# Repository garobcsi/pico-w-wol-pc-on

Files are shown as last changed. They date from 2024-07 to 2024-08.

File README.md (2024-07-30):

# Turn on your pc useing a raspberry pico-w

## Main goal of the project

Some motherboards dosent support wol or just dosent always work,
but useing a pico as the wol reciver (the pico connects to wifi) you could turn on your pc from anywhere in the world if you use port forwarding on your router.

## Thecnical side

### main.c

In `#define` setup your `SSID` `PASSWORD` and your `GPIO_PIN` number has to be configured and then build the firmweare.

#### Building the firmweare

```
cd code
cmake .
make
```

### The pico and motherboard

When the pico recives a magic packet it send a signal to the optocoupler (the pico cannot be on the same ground as your pc) and briges the power button and turns on the pc. But thers a pass truh port that you plug in your existing pc's power button so the pc's power button dosent lose it's function. And the pc can be turn on by existing button and by the pcio.

`Wol in`: pico gpio input
`BT in`: pc case power button
`FP out`: front panel out

## Motherboard pics

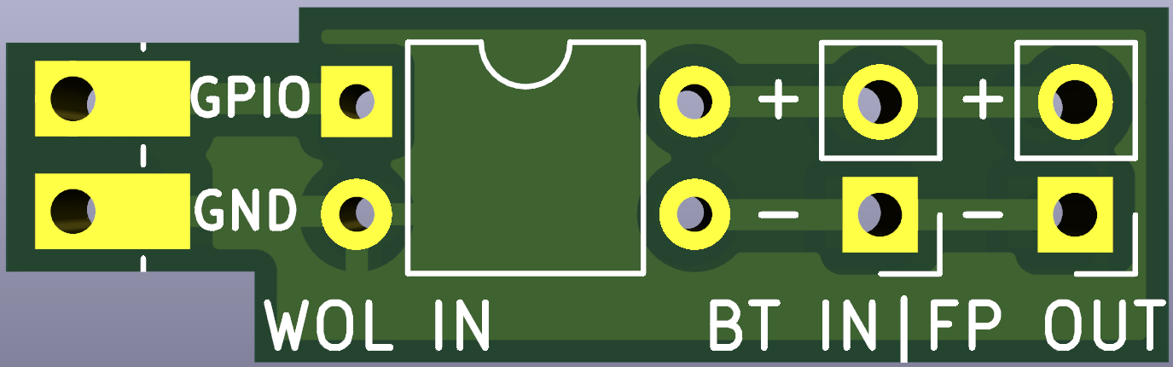
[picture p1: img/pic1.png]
mobo

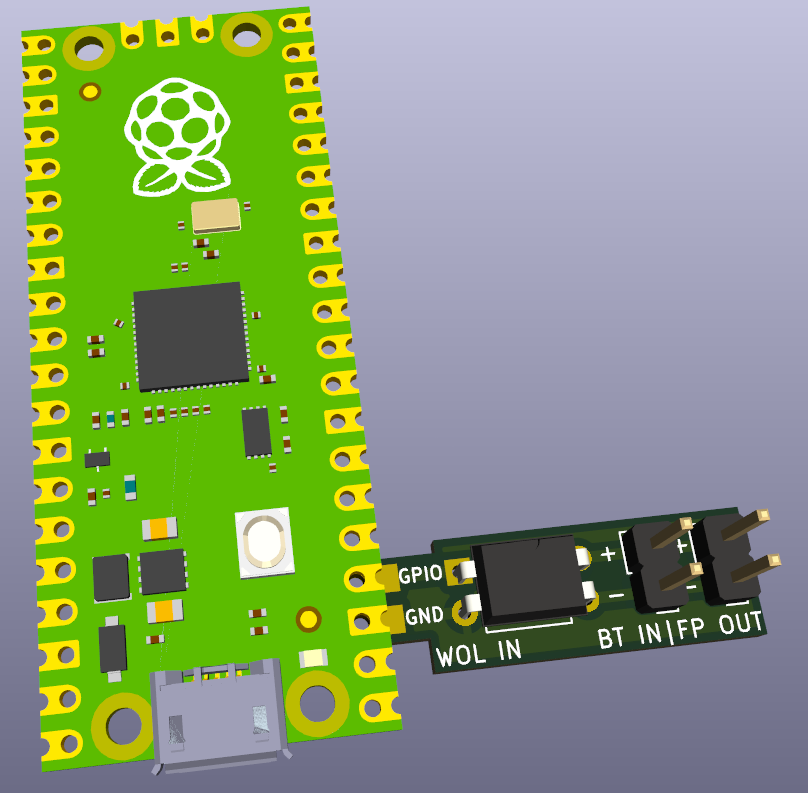
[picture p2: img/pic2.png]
mobo pico


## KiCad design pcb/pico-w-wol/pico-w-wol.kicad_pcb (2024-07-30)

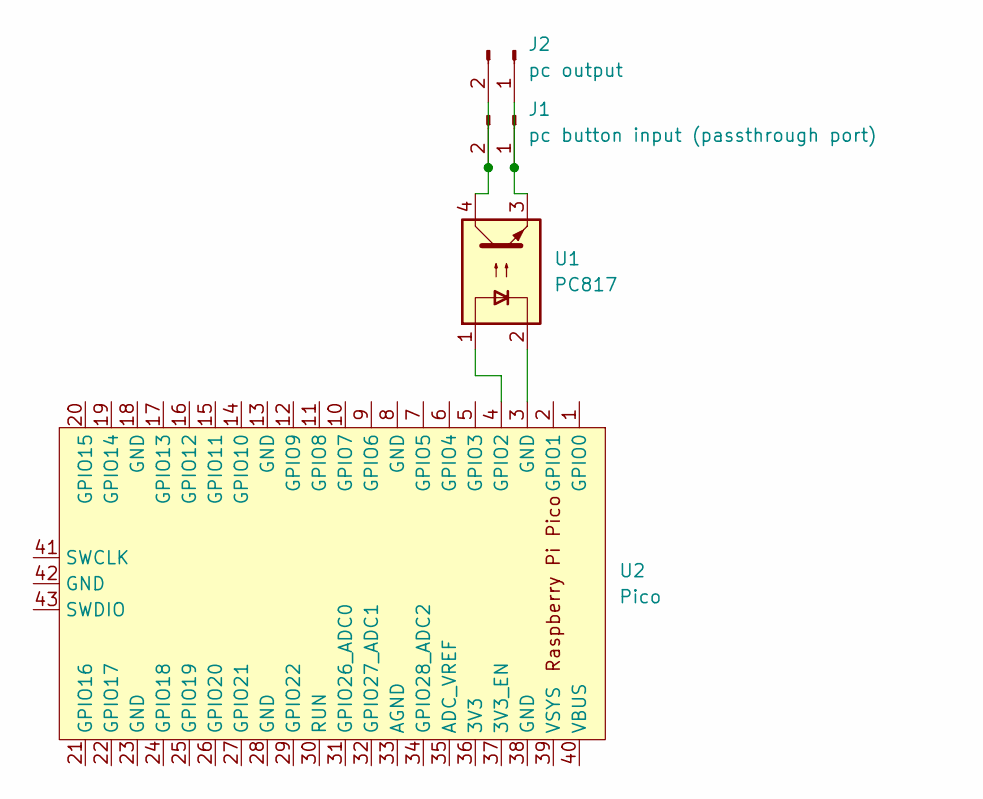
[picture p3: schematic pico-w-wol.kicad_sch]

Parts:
J1: pc button input (passthrough port); PinHeader_1x02_P2.54mm_Vertical
J2: pc output; PinHeader_1x02_P2.54mm_Vertical
U1: PC817; DIP-4_W7.62mm
U2: Pico; RPi_Pico_SMD_TH

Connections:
unnamed: J1.1, J2.1, U1.3
unnamed: J1.2, J2.2, U1.4
unnamed: U1.2, U2.3 (GND)
unnamed: U1.1, U2.4 (GPIO2)

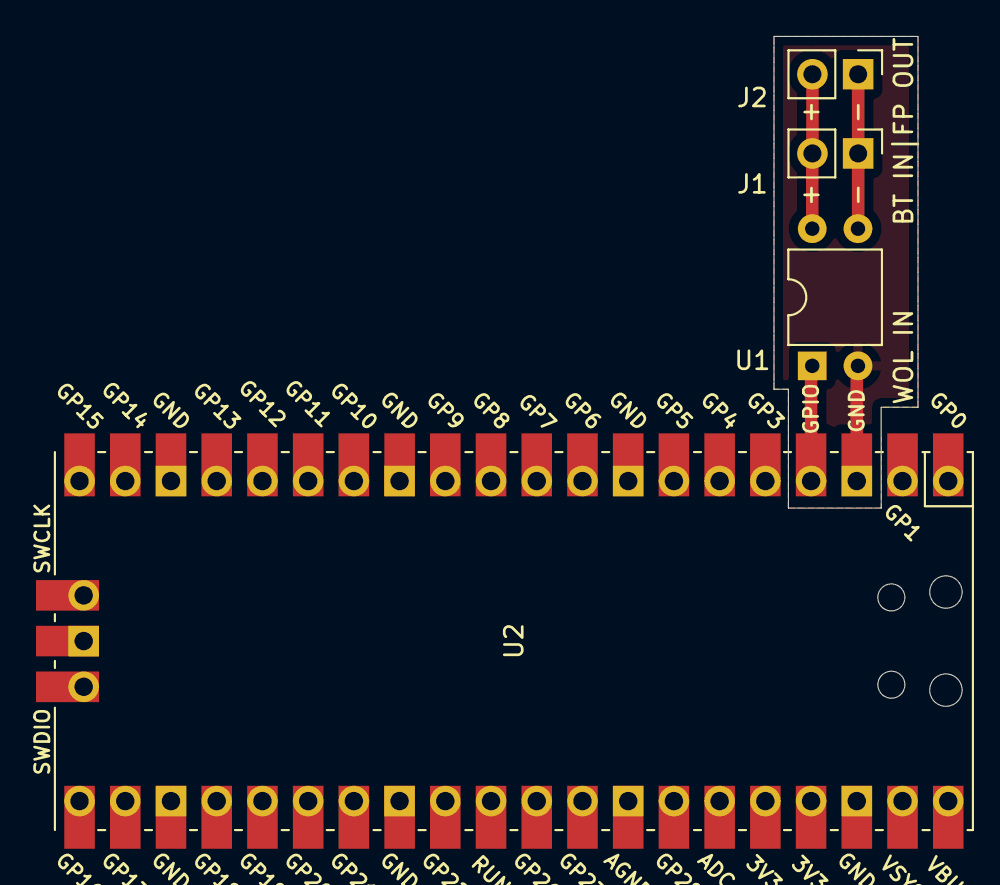
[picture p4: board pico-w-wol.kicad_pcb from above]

Board: 2 copper layers, 4 parts (0 on the bottom side), 4 nets.

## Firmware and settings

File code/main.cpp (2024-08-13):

#include "pico/stdlib.h"
#include "pico/cyw43_arch.h"
#include "lwip/pbuf.h"
#include "lwip/udp.h"

#define STRINGIFY(x) #x
#define STRINGIFY_VALUE(x) STRINGIFY(x)
#define LED_PIN CYW43_WL_GPIO_LED_PIN

// #define TURN_OFF_LIGHT
#define TRUN_OFF_PRINTF

#define WOL_PORT 9  // Standard WoL port
#define GPIO_PIN 14
#define SSID your_ssid
#define PASSWORD your_password

static const uint8_t WOL_MAGIC_HEADER[6] = {0xFF, 0xFF, 0xFF, 0xFF, 0xFF, 0xFF};

void wol_recv(void *arg, struct udp_pcb *pcb, struct pbuf *p, const ip_addr_t *addr, u16_t port) {
    if (p->len == 102) {
        uint8_t *payload = (uint8_t *)p->payload;
        if (memcmp(payload, WOL_MAGIC_HEADER, sizeof(WOL_MAGIC_HEADER)) == 0) {
#ifndef TURN_OFF_LIGHT
            cyw43_arch_gpio_put(LED_PIN, true);
#endif
            gpio_put(GPIO_PIN, true);
            sleep_ms(200);
#ifndef TURN_OFF_LIGHT
            cyw43_arch_gpio_put(LED_PIN, false);
#endif
            gpio_put(GPIO_PIN, false);
            sleep_ms(200);
        }
    }
    pbuf_free(p);
}

void connect_to_wifi() {
    while (cyw43_arch_wifi_connect_timeout_ms(STRINGIFY_VALUE(SSID), STRINGIFY_VALUE(PASSWORD), CYW43_AUTH_WPA2_AES_PSK, 30000) != 0) {
#ifndef TRUN_OFF_PRINTF
        printf("WiFi connection failed, retrying...\n");
#endif
#ifndef TURN_OFF_LIGHT
        cyw43_arch_gpio_put(LED_PIN, true);
#endif
        sleep_ms(5000);  // Wait before retrying
    }
#ifndef TRUN_OFF_PRINTF
    printf("Connected to WiFi\n");
#endif
#ifndef TURN_OFF_LIGHT
    cyw43_arch_gpio_put(LED_PIN, false);
#endif
}

int main() {
    stdio_init_all();
    if (cyw43_arch_init()) {
#ifndef TRUN_OFF_PRINTF
        printf("WiFi init failed\n");
#endif
#ifndef TURN_OFF_LIGHT
        cyw43_arch_gpio_put(LED_PIN, true);
#endif
        return 1;
    }

    gpio_init(GPIO_PIN);
    gpio_set_dir(GPIO_PIN, GPIO_OUT);
    gpio_put(GPIO_PIN, false);

    cyw43_arch_enable_sta_mode();

    connect_to_wifi();

    struct udp_pcb *pcb;
    pcb = udp_new_ip_type(IPADDR_TYPE_ANY);
    if (!pcb) {
#ifndef TRUN_OFF_PRINTF
        printf("Failed to create PCB\n");
#endif
#ifndef TURN_OFF_LIGHT
        cyw43_arch_gpio_put(LED_PIN, true);
#endif
        return 1;
    }

    if (udp_bind(pcb, IP_ADDR_ANY, WOL_PORT) != ERR_OK) {
#ifndef TRUN_OFF_PRINTF
        printf("UDP bind failed\n");
#endif
#ifndef TURN_OFF_LIGHT
        cyw43_arch_gpio_put(LED_PIN, true);
#endif
        udp_remove(pcb);
        return 1;
    }

    udp_recv(pcb, wol_recv, NULL);

    while (true) {
        cyw43_arch_poll();

        // Check if still connected to WiFi
        if (cyw43_tcpip_link_status(&cyw43_state, 0) != CYW43_LINK_UP) {
#ifndef TRUN_OFF_PRINTF
            printf("WiFi connection lost, reconnecting...\n");
#endif
#ifndef TURN_OFF_LIGHT
            cyw43_arch_gpio_put(LED_PIN, true);
#endif
            connect_to_wifi();
        }
    }

    cyw43_arch_deinit();
    return 0;
}

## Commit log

2024-07-29 made wol to led
2024-07-30 moved code and created pcb
    [pico-w-wol.kicad_pcb, pico-w-wol.kicad_sch]
2024-07-30 added blink gpio pin
2024-07-30 Updated pcb labeling
    [pico-w-wol.kicad_pcb]
2024-07-30 Updated silkscreen
    [pico-w-wol.kicad_pcb]
2024-08-01 added wifi conection error handling
    [main.cpp]
